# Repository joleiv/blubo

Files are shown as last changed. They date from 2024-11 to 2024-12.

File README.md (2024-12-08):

# BLUBO
"Blubo" is an advanced sensor for monitoring light pollution in various environments, using Hamamatsu S2386-5K photodiodes and custom transimpedance amplifiers to measure sky brightness. Essential for environmental research and crafting sustainable lighting policies.

## How to setup:

1. On a clean installation of Raspbian 11 Bullseye, install Git and download the repo:
```
git clone https://github.com/joleiv/blubo.git
```
2. After the installation is complete, you must set the file as an executable. Open terminal and run the following code:
````
cd blubo

chmod +x blubo-setup.sh

./blubo-setup.sh
````
3. Follow the instructions in the script.

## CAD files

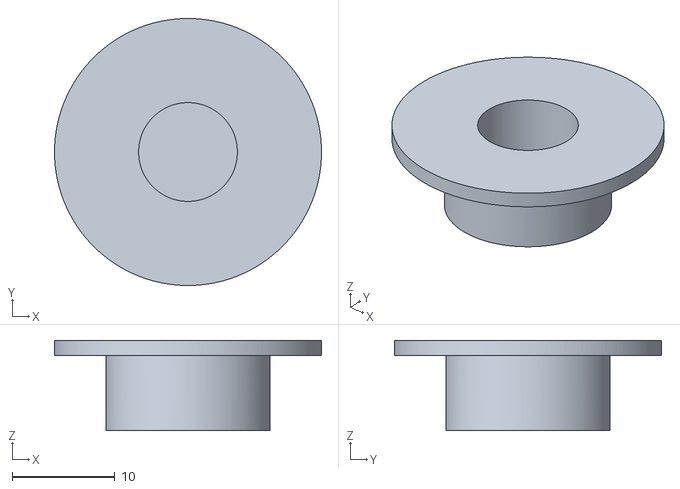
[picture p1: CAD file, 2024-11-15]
stl files/Final-ThreadSoporte.stl
26.0 x 26.0 x 8.80

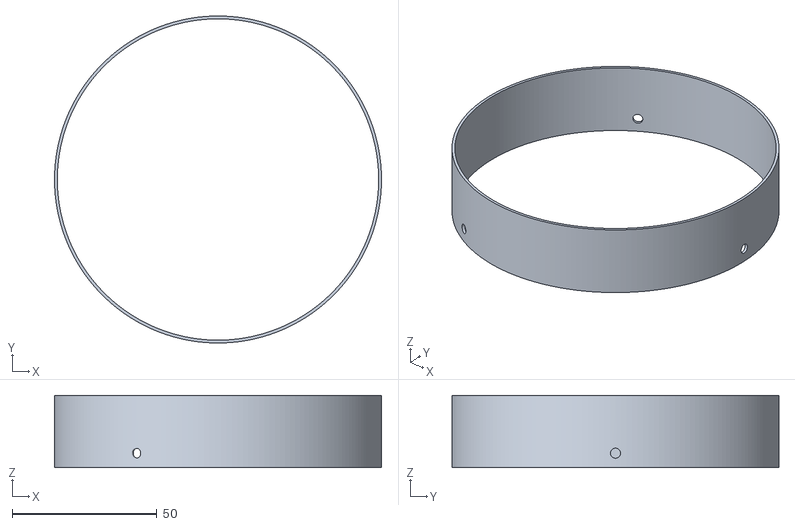
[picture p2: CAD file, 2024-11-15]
stl files/Final-GuiaTornillos.stl
113.0 x 113.0 x 25.0

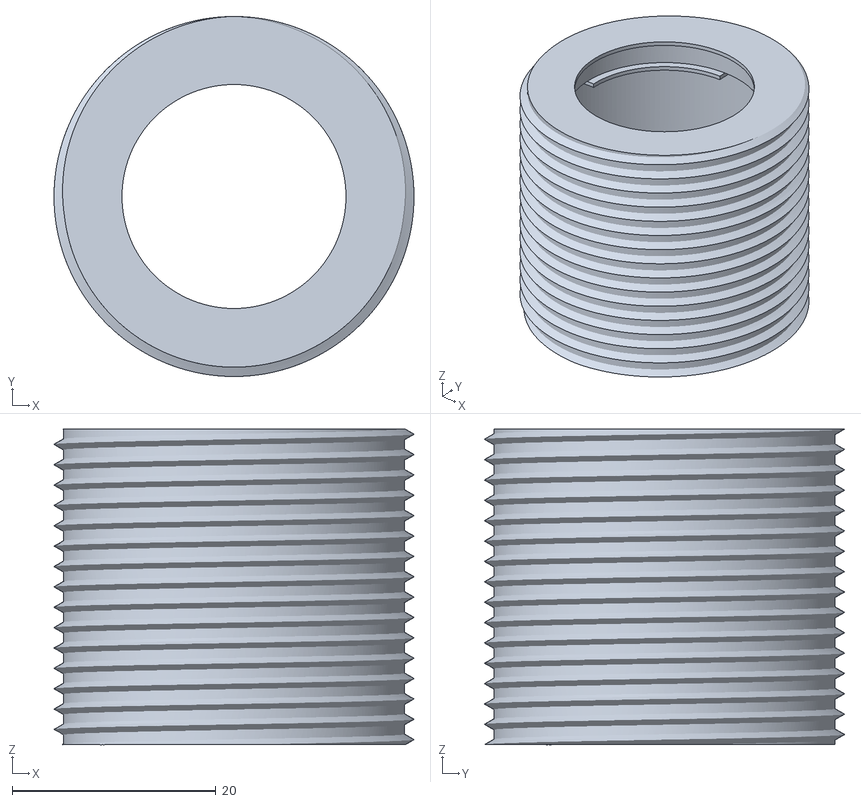
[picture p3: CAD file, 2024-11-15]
stl files/Final-CilindroLente.stl
35.4 x 35.4 x 31.0

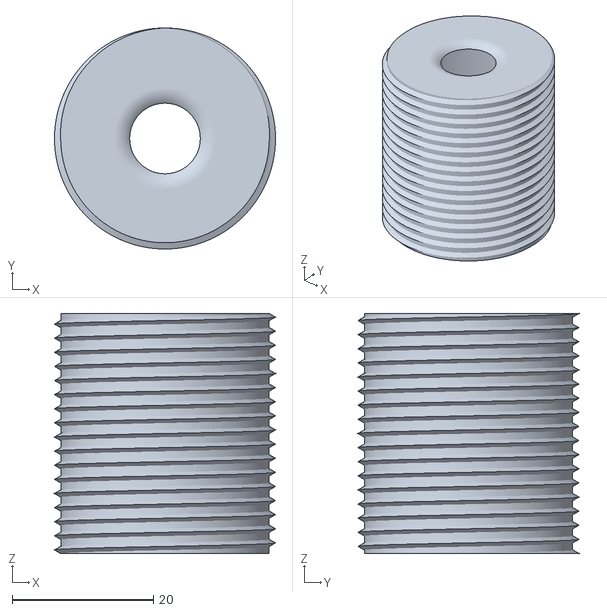
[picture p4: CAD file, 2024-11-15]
stl files/Final-Cilindro.stl
31.3 x 31.3 x 34.0

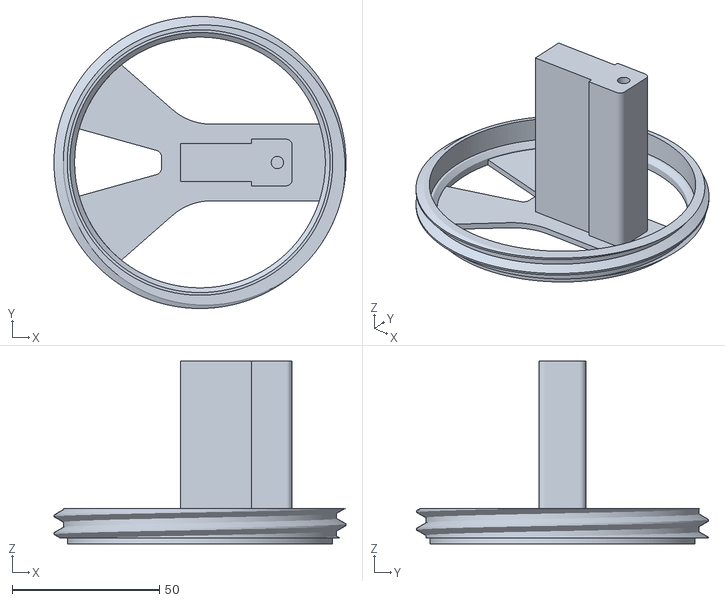
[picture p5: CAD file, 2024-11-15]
stl files/Final-PiezaInterior.stl
99.0 x 99.0 x 62.0

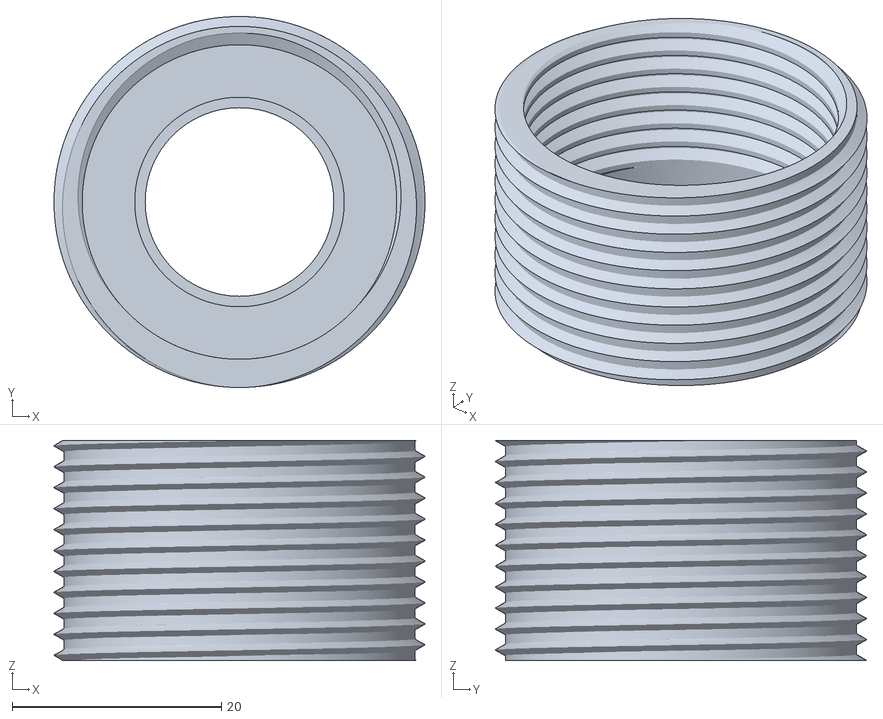
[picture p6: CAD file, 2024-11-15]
stl files/Final-CilindroFiltro.stl
35.4 x 35.4 x 21.0

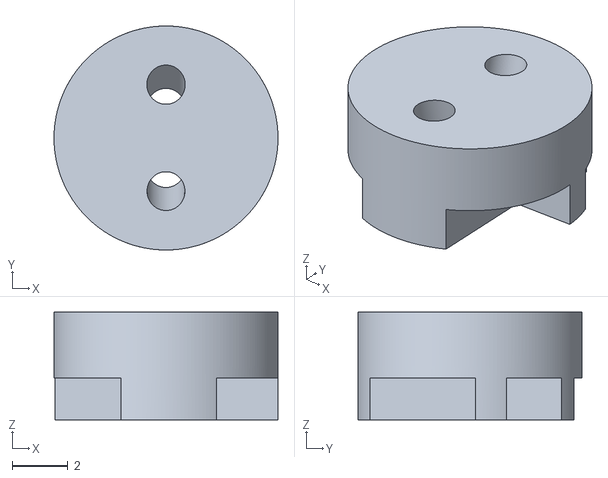
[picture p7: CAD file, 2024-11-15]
stl files/Final-AdaptadorFotodiodo.stl
8.00 x 8.00 x 3.84

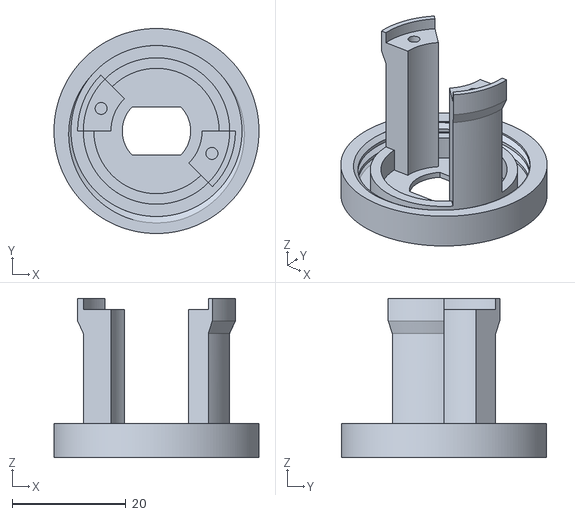
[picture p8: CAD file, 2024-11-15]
stl files/Final-PortaPCBTIA.stl
36.0 x 36.0 x 28.0

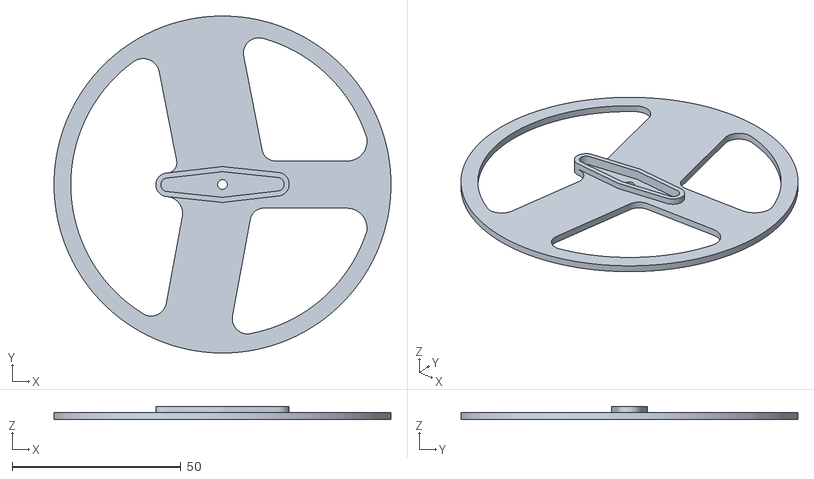
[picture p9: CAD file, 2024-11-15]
stl files/Final-TapaServoHelice.stl
100.0 x 100.0 x 3.80

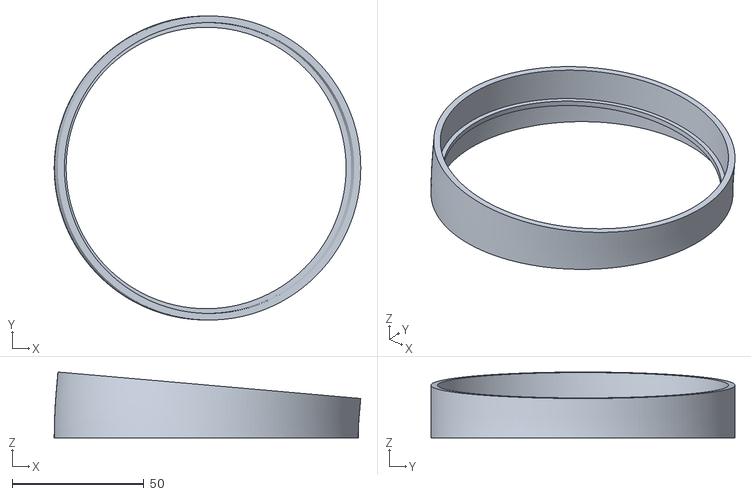
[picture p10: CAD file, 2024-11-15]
stl files/Final-TapaDiagRotada.stl
116.6 x 115.6 x 25.1

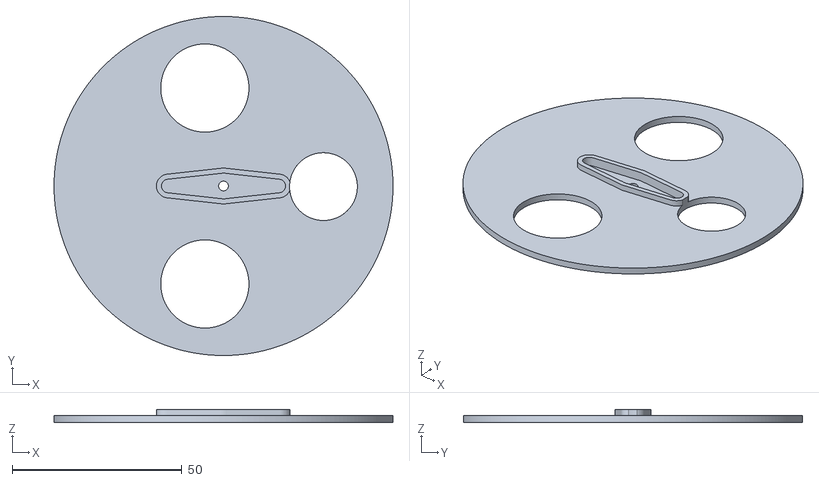
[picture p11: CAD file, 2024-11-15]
stl files/Final-TapaServo.stl
100.0 x 100.0 x 3.80

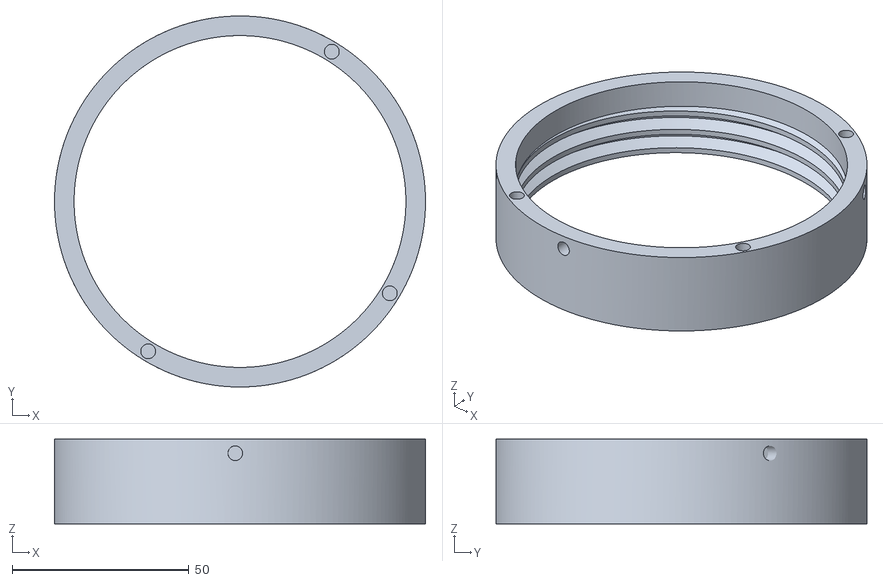
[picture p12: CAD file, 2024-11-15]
stl files/Final-HiloInteriorTubo.stl
105.0 x 105.0 x 24.0

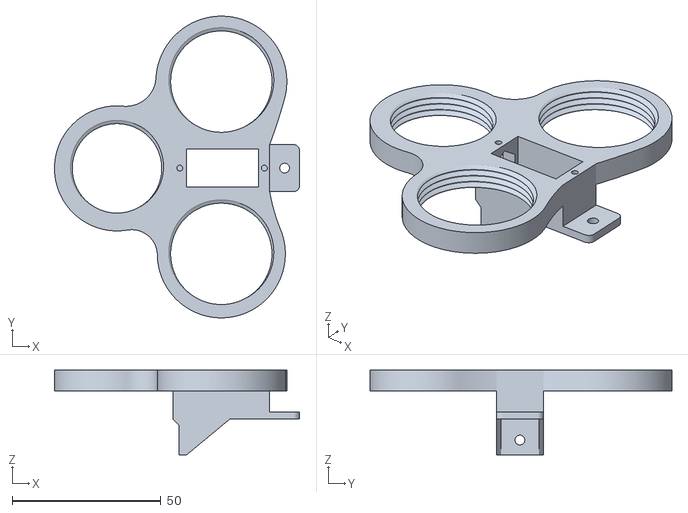
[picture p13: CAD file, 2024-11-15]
stl files/Final-PiezaInteriorCilindros.stl
82.3 x 101.3 x 28.5

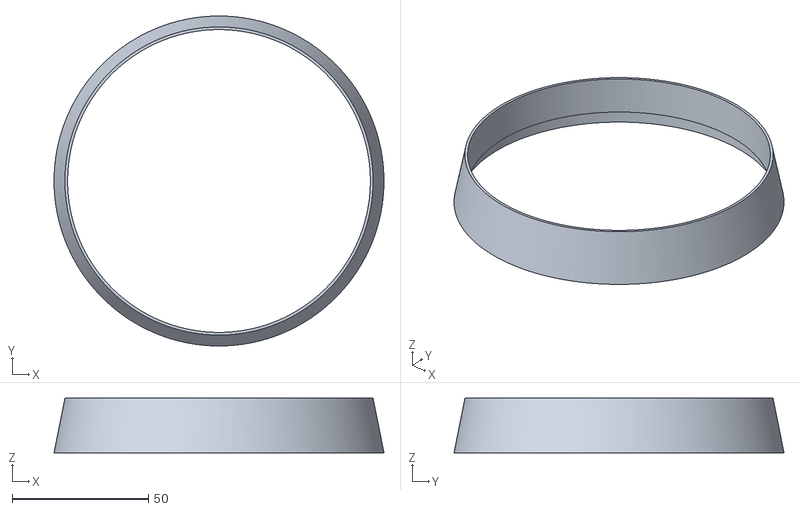
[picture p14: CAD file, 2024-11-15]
stl files/Final-Falda.stl
121.0 x 121.0 x 20.0

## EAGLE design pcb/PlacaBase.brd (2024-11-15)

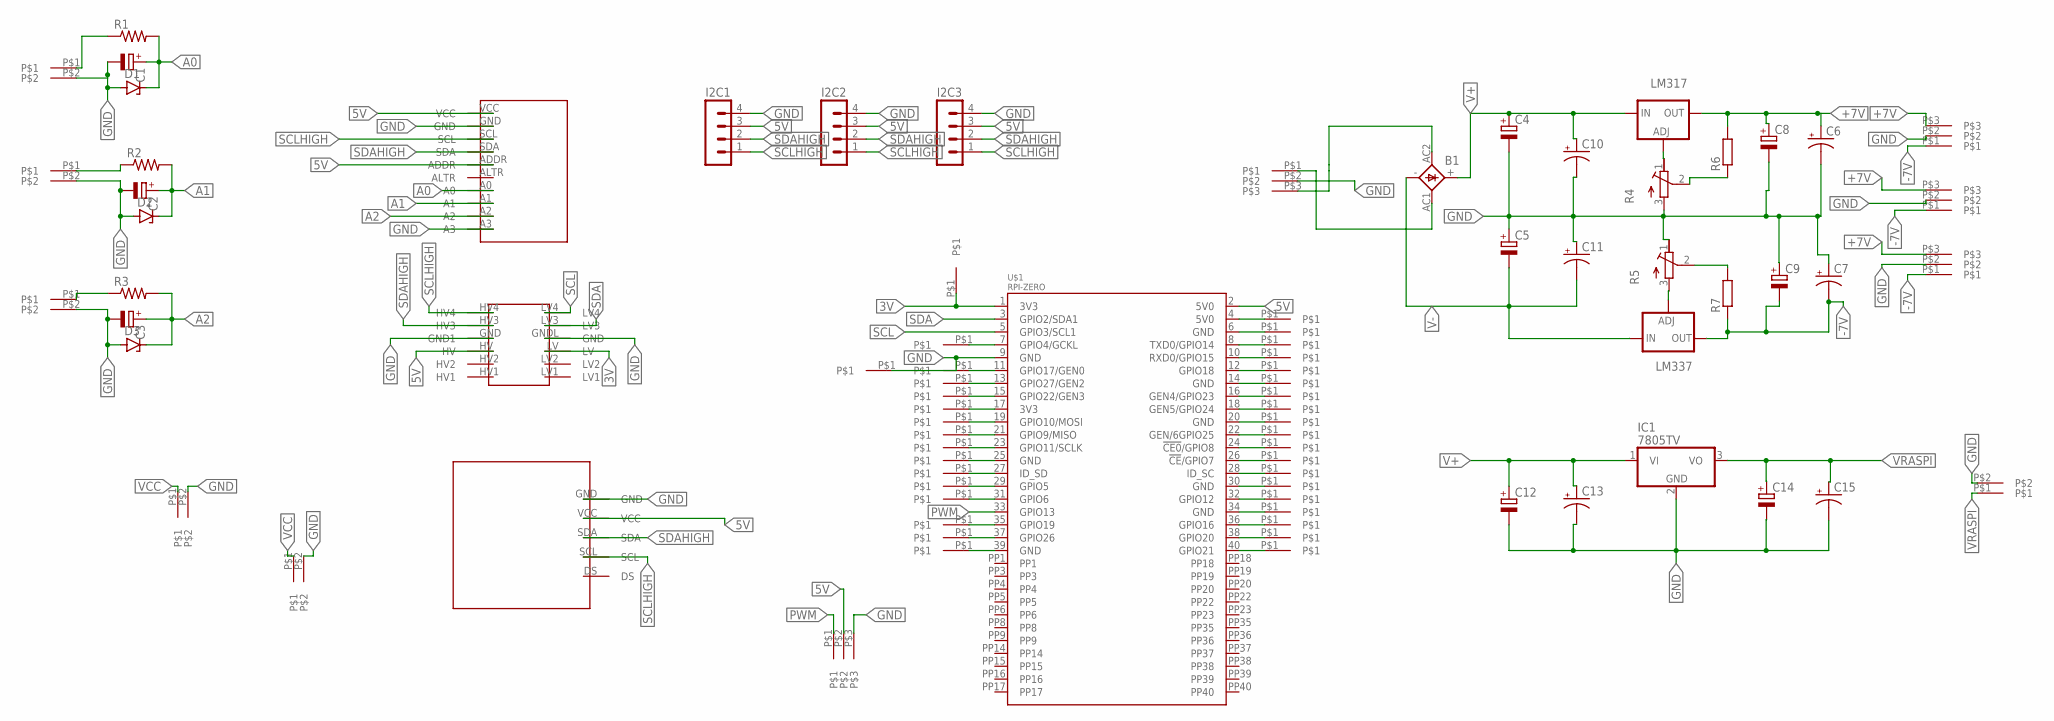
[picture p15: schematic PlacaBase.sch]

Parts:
5VIN: MOLEXPEQUEÑO2P
B1: KBL
C1, C2, C3: CPOL-EUE5-5; E5-5
C4, C5, C12: CPOL-EUE3.5-10; E3,5-10
C6, C7, C10, C11, C13, C15: CPOL-USTAP5-45; TAP5-45
C8, C9, C14: CPOL-EUTT2D7; TT2D7
D1, D2, D3: ZENER-DIODEDO34-7; DO34Z7
ENTRADAAC: MOLEXPEQUEÑO
I2C1, I2C2, I2C3: MA04-1
IC1: 7805TV; TO220V
LM317: LM317TS; 317TS
LM337: LM337TS; 337TS
R1, R2, R3: R-US_0204/5; 0204/5
R4, R5: R-TRIMMT93YA; RTRIMT93YA
R6, R7: R-EU_0207/7; 0207/7
U$1: RPI-ZERO; RASP_PI_ZERO_BOARD_FULL
U$2: ADS1115
U$3: RTC1307
U$4: CONVERSORLOGICO
U$5, U$13, U$14, U$15: MOLEXPEQUEÑO
U$6, U$7, U$8, U$9, U$10: MOLEXPEQUEÑO2P
U$11, U$12, U$16, U$17, U$18, U$19, U$20, U$21, U$22, U$23, U$24, U$25, U$26, U$27, U$28, U$29, U$30, U$31, U$32, U$33, U$34, U$35, U$36, U$37, U$38, U$39, U$40, U$41, U$42, U$43, U$44, U$45, U$46, U$47, U$48, U$49: PUENTE

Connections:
3V: U$1.1 (3V3), U$4.LV, U$48.P$1
3V3@2: U$1.17 (3V3), U$17.P$1
5V: I2C1.3, I2C2.3, I2C3.3, U$1.2 (5V0), U$2.ADDR, U$2.VCC, U$3.VCC, U$4.HV, U$5.P$2
5V0@2: U$1.4 (5V0), U$46.P$1
+7V: C6.+, C8.+, LM317.2 (OUT), R6.2, U$13.P$3, U$14.P$3, U$15.P$3
-7V: C7.-, C9.-, LM337.3 (OUT), R7.1, U$13.P$1, U$14.P$1, U$15.P$1
A0: C1.+, D1.C, R1.2, U$2.A0
A1: C2.+, D2.C, R2.2, U$2.A1
A2: C3.+, D3.C, R3.2, U$2.A2
AC1: B1.AC1 (AC2), ENTRADAAC.P$1
AC2: B1.AC2 (AC1), ENTRADAAC.P$3
GND: 5VIN.P$2, C1.-, C2.-, C3.-, C4.-, C5.+, C6.-, C7.+, C8.-, C9.+, C10.-, C11.+, C12.-, C13.-, C14.-, C15.-, D1.A, D2.A, D3.A, ENTRADAAC.P$2, I2C1.4, I2C2.4, I2C3.4, IC1.2 (GND), R4.3 (A), R5.1 (E), U$1.9 (GND), U$2.A3, U$2.GND, U$3.GND, U$4.GND (GND1), U$4.GNDL (GND), U$5.P$3, U$6.P$2, U$7.P$2, U$8.P$2, U$9.P$2, U$10.P$2, U$13.P$2, U$14.P$2, U$15.P$2, U$49.P$1
GND@2: U$1.25 (GND), U$21.P$1
GND@3: U$1.39 (GND), U$45.P$1
GND@4: U$1.14 (GND), U$29.P$1
GND@5: U$1.20 (GND), U$32.P$1
GND@6: U$1.30 (GND), U$37.P$1
GND@7: U$1.34 (GND), U$39.P$1
GND@8: U$1.6 (GND), U$25.P$1
unnamed: LM317.1 (ADJ), R4.1 (E)
unnamed: U$1.8 (TXD0/GPIO14), U$26.P$1
unnamed: R1.1, U$6.P$1
unnamed: R4.2 (S), R6.1
unnamed: R2.1, U$7.P$1
unnamed: U$1.10 (RXD0/GPIO15), U$27.P$1
unnamed: U$1.12 (GPIO18), U$28.P$1
unnamed: R3.1, U$8.P$1
unnamed: U$1.16 (GEN4/GPIO23), U$30.P$1
unnamed: U$1.18 (GEN5/GPIO24), U$31.P$1
unnamed: U$1.22 (GEN/6GPIO25), U$33.P$1
unnamed: U$1.24 (!CE0!/GPIO8), U$34.P$1
unnamed: LM337.1 (ADJ), R5.3 (A)
unnamed: R5.2 (S), R7.2
unnamed: U$1.26 (!CE!/GPIO7), U$35.P$1
unnamed: U$1.28 (ID_SC), U$36.P$1
unnamed: U$1.32 (GPIO12), U$38.P$1
unnamed: U$1.36 (GPIO16), U$40.P$1
unnamed: U$1.38 (GPIO20), U$41.P$1
unnamed: U$1.40 (GPIO21), U$42.P$1
unnamed: U$1.11 (GPIO17/GEN0), U$11.P$1
unnamed: U$1.13 (GPIO27/GEN2), U$12.P$1
unnamed: U$1.15 (GPIO22/GEN3), U$16.P$1
unnamed: U$1.19 (GPIO10/MOSI), U$18.P$1
unnamed: U$1.21 (GPIO9/MISO), U$19.P$1
unnamed: U$1.23 (GPIO11/SCLK), U$20.P$1
unnamed: U$1.27 (ID_SD), U$22.P$1
unnamed: U$1.29 (GPIO5), U$23.P$1
unnamed: U$1.31 (GPIO6), U$24.P$1
unnamed: U$1.35 (GPIO19), U$43.P$1
unnamed: U$1.37 (GPIO26), U$44.P$1
unnamed: U$1.7 (GPIO4/GCKL), U$47.P$1
PWM: U$1.33 (GPIO13), U$5.P$1
SCL: U$1.5 (GPIO3/SCL1), U$4.LV4
SCLHIGH: I2C1.1, I2C2.1, I2C3.1, U$2.SCL, U$3.SCL, U$4.HV4
SDA: U$1.3 (GPIO2/SDA1), U$4.LV3
SDAHIGH: I2C1.2, I2C2.2, I2C3.2, U$2.SDA, U$3.SDA, U$4.HV3
V+: B1.+, C4.+, C10.+, C12.+, C13.+, IC1.1 (VI), LM317.3 (IN)
V-: B1.-, C5.-, C11.-, LM337.2 (IN)
VCC: 5VIN.P$1, U$10.P$1
VRASPI: C14.+, C15.+, IC1.3 (VO), U$9.P$1

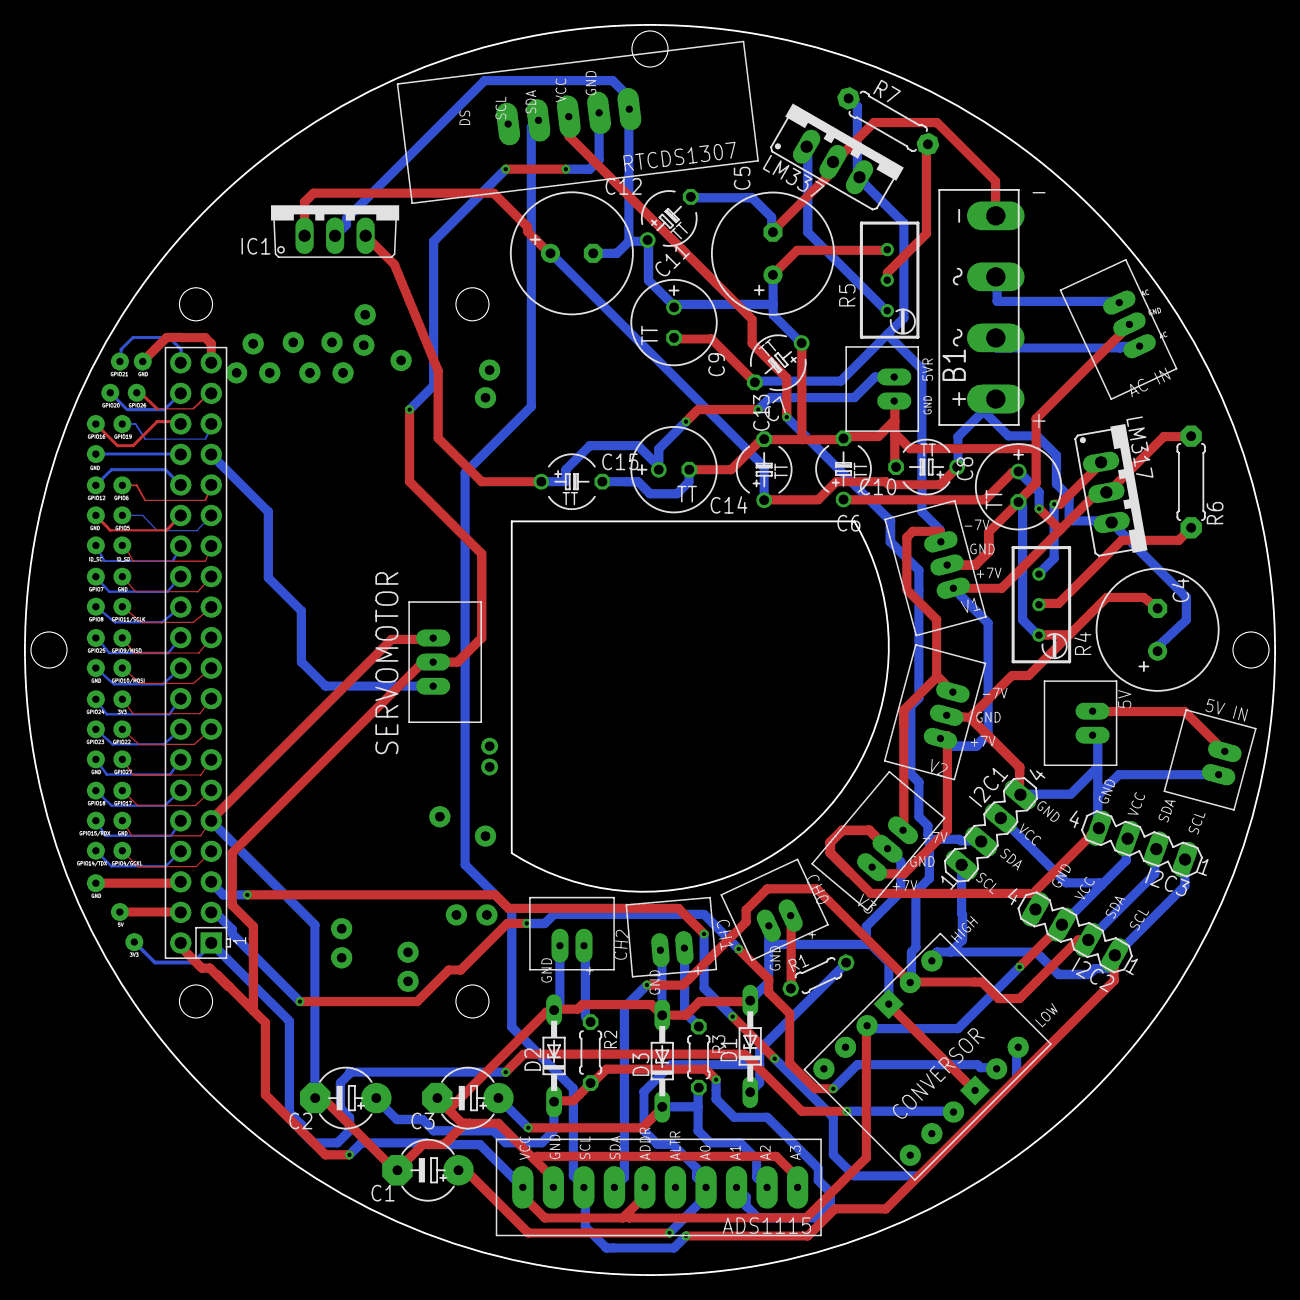
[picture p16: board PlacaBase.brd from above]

Board: 2 copper layers, 104.0 x 104.0 mm, 83 parts (0 on the bottom side), 60 nets.

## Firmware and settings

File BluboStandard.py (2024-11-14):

import pigpio
import time
from datetime import datetime
import signal
import sys
import board
import busio
import threading
import adafruit_ads1x15.ads1115 as ADS
from adafruit_ads1x15.analog_in import AnalogIn
from Adafruit_IO import MQTTClient
import subprocess
import logging
from os import system
import RPi.GPIO as GPIO
import time

def check_pigpiod():
    try:
        subprocess.check_output(["pidof", "pigpiod"])
        return True
    except subprocess.CalledProcessError:
        return False
    
if not check_pigpiod():
    print("'pigpiod' esta desactivado")
    sys.exit(1)

# Configuración
SERVO_PIN = 13
ADAFRUIT_AIO_USERNAME = "blubo"
ADAFRUIT_AIO_KEY = "aio_LNaD94EBm2Xx70S8YfizyLUJI84A"
MAX_RECONNECTION_ATTEMPTS = 10
CHECK_WIFI_INTERVAL = 60  # seconds
PUBLISH_INTERVAL = 15  # seconds
TIME_TO_CLOSE_START = "08:00:00"
TIME_TO_CLOSE_END = "17:30:00"
FILE_HEADER = 'tiempo (unix-time), canal 1 (counts), canal 2 (counts), canal 3 (counts)\n'
PING_SERVER = "8.8.8.8"  # Google DNS server
file_open = False
baconFile = None
current_filename = None
header_info = """
#HEADER
# Device type: 
# Instrument ID: 
# Data supplier:
# Location name: 
# Position: 
# Local timezone: UTC
# Time Synchronization: 
# Moving / Stationary position: STATIONARY
# Moving / Fixed look direction:
# Number of channels:3
# Filters per channel:1
# Measurement direction per channel: 
# Field of view:
# Number of fields per line: 
# Device specific characteristics:
# UTC Date & Time, Local Date & Time, R, G, B meanADU 
# YYYY-MM-DDTHH:mm:ss.fff;YYYY-M
# END OF HEADER"""
        

# Configuración de registro
logging.basicConfig(filename='app.log', level=logging.DEBUG, format='%(asctime)s - %(levelname)s - %(message)s')

# Inicializar PWM para el servo
pwm = pigpio.pi()

def set_servo_angle(angle):
    pulse_width = int((angle / 180.0) * (2500 - 500) + 500)
    pwm.set_servo_pulsewidth(SERVO_PIN, pulse_width)

def is_time_to_close():
    now = datetime.now().time()
    start_time = datetime.strptime(TIME_TO_CLOSE_START, "%H:%M:%S").time()
    end_time = datetime.strptime(TIME_TO_CLOSE_END, "%H:%M:%S").time()
    return start_time <= now <= end_time

def disconnected(client):
    print('Desconectado de Adafruit IO!')

# Inicializar cliente MQTT
client = MQTTClient(ADAFRUIT_AIO_USERNAME, ADAFRUIT_AIO_KEY)
client.connect()
time.sleep(1)
client.loop_background()

# Inicializar ADS1115
def init_ads():
    try:
        i2c = busio.I2C(board.SCL, board.SDA)
        ads = ADS.ADS1115(i2c, address=0x49)
        return [AnalogIn(ads, ADS.P0), AnalogIn(ads, ADS.P1), AnalogIn(ads, ADS.P2)]
    except Exception as e:
        logging.error(f"Error initializing ADS: {e}")
        sys.exit(1)

channels = init_ads()

def signal_handler(sig, frame):
    print('\nKill command received from keyboard - script exiting')
    pwm.set_servo_pulsewidth(SERVO_PIN, 0)
    time.sleep(1)
    sys.exit(0)

# Inicializar archivos
try:
    tiempo_inicio = time.strftime("%Y%m%dT%H%M%S")
    with open(f'{tiempo_inicio}_SKYGLOW_LABSENS.txt', 'w') as baconFile1:
        baconFile1.write('tiempo (unix-time), canal 1 (counts), canal 2 (counts), canal 3 (counts), tsl (lux)\n')

    with open(f'{tiempo_inicio}_SECOND_SKYGLOW_LABSENS.txt', 'w') as baconFile2:
        baconFile2.write(f'{header_info}\n')

except Exception as e:
    print(f"Error initializing files: {e}")
    sys.exit(1)

# Función para escribir en los archivos
def write_to_files(timestamp, values):
    utc_formato = datetime.utcnow().strftime('%Y-%m-%dT%H:%M:%S.%f')[:-3]
    local_formato = datetime.now().strftime('%Y-%m-%dT%H:%M:%S.%f')[:-3]
    
    # Escribir en el primer archivo
    with open(f'{tiempo_inicio}_SKYGLOW_LABSENS.txt', 'a') as baconFile1:
        baconFile1.write(f'{timestamp},{values[0]},{values[1]},{values[2]}\n')
    
    # Escribir en el segundo archivo
    with open(f'{tiempo_inicio}_SECOND_SKYGLOW_LABSENS.txt', 'a') as baconFile2:
        baconFile2.write(utc_formato + ";" + local_formato + ";" + ";".join(map(str, values)) + "\n")


signal.signal(signal.SIGINT, signal_handler)

def ping_server(server):
    try:
        response = subprocess.run(['ping', '-c', '1', server], stdout=subprocess.PIPE, stderr=subprocess.PIPE)
        return response.returncode == 0
    except Exception as e:
        logging.error(f"Error executing ping: {e}")
        return False

def check_wifi_connection(client):
    reconnection_attempts = 0
    while True:
        if not ping_server(PING_SERVER):
            logging.warning("No internet connection. Attempting to reconnect...")
            while reconnection_attempts < MAX_RECONNECTION_ATTEMPTS:
                try:
                    if not client.is_connected():
                        client = MQTTClient(ADAFRUIT_AIO_USERNAME, ADAFRUIT_AIO_KEY)
                        client.connect()
                        logging.info('Reconexión exitosa a Adafruit IO')
                    break
                except Exception as e:
                    logging.error(f"Error al intentar reconectar a Adafruit IO: {e}")
                    reconnection_attempts += 1
                    logging.info(f'Intento de reconexión número {reconnection_attempts}/{MAX_RECONNECTION_ATTEMPTS}.')
                    time.sleep(30)
            else:
                logging.warning('No se pudo reconectar después de varios intentos. Continuando sin conexión a Adafruit IO.')
        else:
            if not client.is_connected():
                try:
                    client.connect()
                    logging.info('Reconexión exitosa a Adafruit IO')
                except Exception as e:
                    logging.error(f"Error al intentar reconectar a Adafruit IO: {e}")
        time.sleep(CHECK_WIFI_INTERVAL)

def wifi_reconnection_thread():
    threading.Thread(target=check_wifi_connection, args=(client,), daemon=True).start()

def main():
    # Iniciar hilo de reconexión de WiFi
    wifi_reconnection_thread()
    
    tiempo_ultima_publicacion = time.time()
    
    while True:
        try:
            timestamp = time.time()
            values = [chan.value for chan in channels]
            voltages = ["%0.4f" % chan.voltage for chan in channels]

            print("\t\t\tCH01\tCH02\tCH03")
            print(f'{time.strftime("[%Y-%m-%d %H:%M:%S]")}\t{voltages[0]}\t{voltages[1]}\t{voltages[2]}')
            
            write_to_files(timestamp, values)

            if time.time() - tiempo_ultima_publicacion >= PUBLISH_INTERVAL:
                if client.is_connected():
                    try:
                        for i, value in enumerate(values, start=1):
                            client.publish(f'blubo.chan {i}', value)
                    except Exception as e:
                        logging.error(f"Error publishing to Adafruit IO: {e}")
                
                tiempo_ultima_publicacion = time.time()

            if is_time_to_close():
                set_servo_angle(92)
            else:
                set_servo_angle(37)

            time.sleep(1)

        except Exception as e:
            print(f"An error occurred: {e}")

if __name__ == "__main__":
    main()

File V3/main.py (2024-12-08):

#!/usr/bin/env python3

from config_manager import ConfigManager
from servo_controller import PigpioServoController
from ads_reader import ADSReader
from file_writer import FileWriter
from servo_pattern_player import ServoPatternPlayer
from logic_controller import LogicController
from rtc import RTC  # Asumiendo que tienes esta clase para la sincronización

def main():
    # Configurar logging, verificar pigpiod, etc.
    # ...

    config = ConfigManager()
    servo = PigpioServoController(servo_pin=config.get("servo_pin", 13))
    ads_reader = ADSReader()

    # Instanciar RTC y sincronizar hora si es necesario
    rtc = RTC()
    rtc.sync_system_time()  # Ajusta la hora del sistema con el RTC
    last_rtc_update = rtc.read_current_time()  # Leer la hora actual del RTC para el header

    file_writer = FileWriter(config, last_rtc_update)
    error_patterns = config.get("error_patterns", {})
    servo_pattern_player = ServoPatternPlayer(servo, error_patterns)

    logic = LogicController(config, servo, ads_reader, file_writer, servo_pattern_player)
    # Manejo de señal SIGINT
    # ...

    logic.run()

if __name__ == "__main__":
    main()

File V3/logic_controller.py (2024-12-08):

import time
import logging
import sys
from datetime import datetime

class LogicController:
    """
    Controla la lógica principal de la aplicación: leer datos, escribir en archivos,
    controlar el servo según la hora, y responder a errores.
    """
    def __init__(self, config, servo_controller, ads_reader, file_writer, servo_pattern_player):
        self.config = config
        self.servo = servo_controller
        self.ads_reader = ads_reader
        self.file_writer = file_writer
        self.servo_pattern_player = servo_pattern_player

        self.time_to_close_start = self.config.get("time_to_close_start", "08:00:00")
        self.time_to_close_end = self.config.get("time_to_close_end", "17:30:00")

        # Valores de ángulo desde el config
        self.angle_closed = self.config.get("angle_closed", 92)
        self.angle_open = self.config.get("angle_open", 37)

        # Estado interno del servo
        self.current_servo_angle = None

    def is_time_to_close(self):
        now = datetime.now().time()
        start_time = datetime.strptime(self.time_to_close_start, "%H:%M:%S").time()
        end_time = datetime.strptime(self.time_to_close_end, "%H:%M:%S").time()
        return start_time <= now <= end_time

    def run(self):
        # Al iniciar, podemos reproducir un patrón (por ejemplo "device_on")
        self.servo_pattern_player.play("device_on")
        time.sleep(5)

        while True:
            try:
                timestamp = time.time()
                values, voltages = self.ads_reader.read_values()

                # Impresión de datos
                print("\t\t\tCH01\tCH02\tCH03")
                print(f'{time.strftime("[%Y-%m-%d %H:%M:%S]")}\t{voltages[0]}\t{voltages[1]}\t{voltages[2]}')

                # Escritura en archivos
                self.file_writer.write_data(timestamp, values)

                # Determinar el ángulo deseado según la hora
                if self.is_time_to_close():
                    desired_angle = self.angle_closed
                else:
                    desired_angle = self.angle_open

                # Cambiar el ángulo del servo sólo si es diferente al actual
                if self.current_servo_angle != desired_angle:
                    self.servo.set_servo_angle(desired_angle)
                    self.current_servo_angle = desired_angle

                time.sleep(1)

            except Exception as e:
                logging.error(f"An error occurred: {e}")
                # Ejemplo: reproducir patrón de error_1
                self.servo_pattern_player.play("error_1")

    def stop(self):
        """
        Llamado cuando se recibe SIGINT u otra señal para terminar.
        """
        self.servo.stop_servo()
        sys.exit(0)

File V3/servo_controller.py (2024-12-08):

import pigpio
import sys
import time

class PigpioServoController:
    """
    Controla el servo a través de la librería pigpio.
    """
    def __init__(self, servo_pin=13):
        self.servo_pin = servo_pin
        self.pwm = pigpio.pi()
        if not self.pwm.connected:
            print("Error: No se pudo conectar a pigpiod.")
            sys.exit(1)
        
    def set_servo_angle(self, angle):
        """
        Ajusta el servo a un ángulo dado (0 a 180).
        """
        pulse_width = int((angle / 180.0) * (2500 - 500) + 500)
        self.pwm.set_servo_pulsewidth(self.servo_pin, pulse_width)
        
    def stop_servo(self):
        """
        Detiene el servo.
        """
        self.pwm.set_servo_pulsewidth(self.servo_pin, 0)
        time.sleep(1)

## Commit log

2024-12-08 Se agrega ejecucion auto de main.py
2024-12-08 Correccion Servo
2024-12-08 Corregido Angulo Servo
